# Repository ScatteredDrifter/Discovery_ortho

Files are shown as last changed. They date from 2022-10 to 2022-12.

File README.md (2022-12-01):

# SO[H] ORTHO!

A 52 key (4x14) ortholinear keyboard, powered by an RP2040

This is a fork of [Horizon by skarrmann](https://github.com/skarrmann/horizon)

Used License [MIT](/LICENSE)

 ---
This keyboard is a grid of 1U keys with optional hotswap, breakout for LED-backlighting.



## Status :: 
- prototypes arrived and **working**
- Case to be tested 
- untested LEDs
- untested LED-Pinout
- working encoder  

---

## Features :: 
- QMK and Vial Support
- Support for Choc-Switches **only**!
- Choc-spacing 
- Hotswap for Choc-Switches 
- built with rp2040 and additional flash storage allowing for plenty of combos, layers, led matrices etc.
- easy to order with jlcpcb --> check release for files 
- support for encoder in the middle  
- additional pinouts for further modifications 
- middle part features several layouts

## Layout :: 

This pcb features different layouts that are configured within VIAL for easy usage. See below for available Layout-Options. 

As for the case, there are 6 screw holes for mounting a panel in the middle to cover the electronics. 

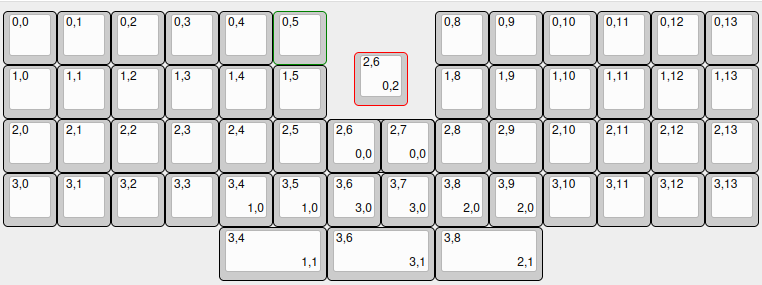
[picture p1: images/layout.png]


## Firmware :: 

the pre-compiled file for Vial and the whole Qmk-userspace for this keyboard can be found [here](/firmware/)

To enter the bootloader - which is necessary in order to flash a new firmware - you'll have to bridge the two contacts located in the middle of the front-pcb. In later revisions there might be actual buttons, for the first revision I was not able to get them to fit on there. Bridge both contacts for a short amount of time in order to boot the mcu to bootloader. It should show up as a regular usb-stick in your file explorer now and you can drag the .utf onto this usb-stick. Once done it will restart and use your newly flashed firmware!

## Images of PCB ::





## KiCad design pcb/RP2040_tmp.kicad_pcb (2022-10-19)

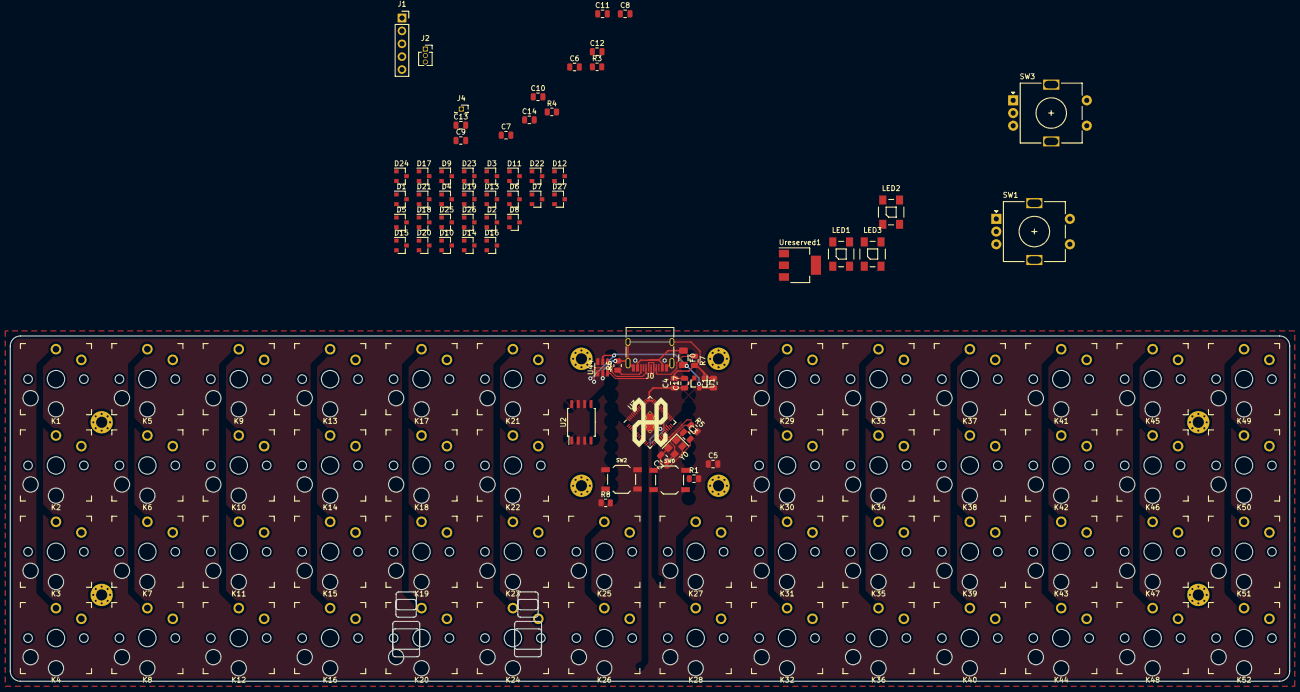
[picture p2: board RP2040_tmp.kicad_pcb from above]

Board: 2 copper layers, 252.0 x 68.0 mm, 129 parts (1 on the bottom side), 99 nets.

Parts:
C1, C4, C17: 10u; C_0805_2012Metric
C2, C3: 22pf; C_0805_2012Metric
C5, C6, C7, C9, C11, C12, C13, C14: 100n; C_0805_2012Metric
C8, C10: 1u; C_0805_2012Metric
D1, D2, D3, D4, D5, D6, D7, D8, D9, D10, D11, D12, D13, D14, D15, D16, D17, D18, D19, D20, D21, D22, D23, D24, D25, D26, D27: BAV70; SOT-23
F0: polyfuse; Fuse_1206_3216Metric
H1, H2, H3, H4, H5, H6, H7, H8: Hole_Pad; Mount_M2
J0: USB_C_Receptacle_USB2.0; USB_C_Receptacle_HRO_TYPE-C-31-M-12
J1: BREAKOUT; PinSocket_1x05_P2.54mm_Vertical
J2: Conn_01x03_Male; PinSocket_1x03_P1.27mm_Vertical
J4: Conn_01x01_Male; PinSocket_1x01_P1.27mm_Vertical
K1, K2, K3, K4, K5, K6, K7, K8, K9, K10, K11, K12, K13, K14, K15, K16, K17, K18, K19, K20, K21, K22, K23, K24, K25, K26, K27, K28, K29, K30, K31, K32, K33, K34, K35, K36, K37, K38, K39, K40, K41, K42, K43, K44, K45, K46, K47, K48, K49, K50, K51, K52: KEYSW; Kailh_socket_PG1350_optional
LED1, LED2, LED3: WS2812B
LOGO1: Logo-Bottom; Logo_Horizon_Small
LOGO2: Logo-Top; Logo_Horizon_H
R1, R5: 1k; R_0805_2012Metric
R3, R4: 27; R_0805_2012Metric
R6, R7: 5.1k; R_0805_2012Metric
R8: 10k; R_0805_2012Metric
SW0, SW2: RESET; SW_SPST_TL3342
SW1, SW3: RotaryEncoder_Switch; RotaryEncoder_Alps_EC11E-Switch_Vertical_H20mm
U1: XC6206 smaller footprint; SOT-23
U2: W25Q128JVS; SOIC-8_5.23x5.23mm_P1.27mm
U3: RP2040; RP2040-QFN-56
U44: SRV05-4; SOT-23-6
Ureserved1: larger footprint, more mA available; SOT-223-3_TabPin2
Y0: 12MHZ Crystal; Crystal_SMD_3225-4Pin_3.2x2.5mm

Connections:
+1V1: C6.1, C7.1, C8.1, J4.1, U3.23 (DVDD), U3.45 (VREG_VOUT), U3.50 (DVDD)
+3V3: C4.1, C5.1, C9.1, C10.1, C11.1, C12.1, C13.1, C14.1, C17.1, J1.2, R8.2, U1.2 (VO), U2.8 (VCC), U3.1 (IOVDD), U3.10 (IOVDD), U3.22 (IOVDD), U3.33 (IOVDD), U3.42 (IOVDD), U3.43 (ADC_AVDD), U3.44 (VREG_IN), U3.48 (USB_VDD), U3.49 (IOVDD)
+5V: C1.1, F0.2, J2.1, LED1.1 (VCC), LED2.1 (VCC), LED3.1 (VCC), U1.3 (VI), U44.5 (VP)
/QSPI_SCLK: U2.6 (CLK), U3.52 (QSPI_SCLK)
/QSPI_SD0: U2.5 (DI(IO0)), U3.53 (QSPI_SD0)
/QSPI_SD1: U2.2 (DO(IO1)), U3.55 (QSPI_SD1)
/QSPI_SD2: U2.3 (IO2), U3.54 (QSPI_SD2)
/QSPI_SD3: U2.7 (IO3), U3.51 (QSPI_SD3)
/QSPI_SS: R1.1, U2.1 (~CS), U3.56 (QSPI_SS)
/RUN: J1.1, R8.1, SW2.2, U3.26 (RUN)
/SWCLK: J1.5, U3.24 (SWCLK)
/SWD: J1.4, U3.25 (SWD)
/USB_D+: J0.A6 (D+), J0.B6 (D+), R3.1, U44.4 (IO3)
/USB_D-: J0.A7 (D-), J0.B7 (D-), R4.1, U44.3 (IO2)
/XIN: C2.1, U3.20 (XIN), Y0.3
/XOUT: R5.1, U3.21 (XOUT)
/~USB_BOOT: R1.2, SW0.2
COL0: K1.2, K2.2, K3.2, K4.2, U3.37 (GPIO25)
COL1: K5.1, K6.1, K7.1, K8.1, U3.36 (GPIO24)
COL2: K9.2, K10.2, K11.2, K12.2, U3.35 (GPIO23)
COL3: K13.1, K14.1, K15.1, K16.1, U3.34 (GPIO22)
COL4: K17.2, K18.2, K19.2, K20.2, U3.32 (GPIO21)
COL5: K21.1, K22.1, K23.1, K24.1, U3.31 (GPIO20)
COL6: K25.2, K26.2, SW1.S2, U3.30 (GPIO19)
COL7: K27.1, K28.1, SW3.S1, U3.29 (GPIO18)
COL8: K29.2, K30.2, K31.2, K32.2, U3.28 (GPIO17)
COL9: K33.1, K34.1, K35.1, K36.1, U3.27 (GPIO16)
COL10: K37.2, K38.2, K39.2, K40.2, U3.18 (GPIO15)
COL11: K41.1, K42.1, K43.1, K44.1, U3.17 (GPIO14)
COL12: K45.2, K46.2, K47.2, K48.2, U3.15 (GPIO12)
COL13: K49.1, K50.1, K51.1, K52.1, U3.14 (GPIO11)
GND: C1.2, C2.2, C3.2, C4.2, C5.2, C6.2, C7.2, C8.2, C9.2, C10.2, C11.2, C12.2, C13.2, C14.2, C17.2, J0.A1 (GND), J0.A12 (GND), J0.B1 (GND), J0.B12 (GND), J0.S1 (SHIELD), J1.3, J2.2, LED1.3 (GND), LED2.3 (GND), LED3.3 (GND), R6.2, R7.2, SW0.1, SW1.C, SW2.1, SW3.C, U1.1 (GND), U2.4 (GND), U3.19 (TESTEN), U3.57 (GND), U44.2 (VN), Y0.2, Y0.4
LED_GLOW: J2.3, LED1.4 (DIN), U3.8 (GPIO6)
unnamed: C3.1, R5.2, Y0.1
unnamed: D1.1 (A), K1.1
unnamed: D1.2 (A), K5.2
unnamed: D2.1 (A), K2.1
unnamed: D2.2 (A), K6.2
unnamed: D3.1 (A), K3.1
unnamed: D3.2 (A), K7.2
unnamed: D4.1 (A), K4.1
unnamed: D4.2 (A), K8.2
unnamed: D5.1 (A), K9.1
unnamed: D5.2 (A), K13.2
unnamed: D6.1 (A), K10.1
unnamed: D6.2 (A), K14.2
unnamed: D7.1 (A), K11.1
unnamed: D7.2 (A), K15.2
unnamed: D8.1 (A), K12.1
unnamed: D8.2 (A), K16.2
unnamed: D9.1 (A), K17.1
unnamed: D9.2 (A), K21.2
unnamed: D10.1 (A), K18.1
unnamed: D10.2 (A), K22.2
unnamed: D11.1 (A), K19.1
unnamed: D11.2 (A), K23.2
unnamed: D12.1 (A), K20.1
unnamed: D12.2 (A), K24.2
unnamed: D13.1 (A), SW1.S1
unnamed: D13.2 (A), SW3.S2
unnamed: D14.1 (A), K25.1
unnamed: D14.2 (A), K27.2
unnamed: D15.1 (A), K26.1
unnamed: D15.2 (A), K28.2
unnamed: D16.1 (A), K29.1
unnamed: D16.2 (A), K33.2
unnamed: D17.1 (A), K30.1
unnamed: D17.2 (A), K34.2
unnamed: D18.1 (A), K31.1
unnamed: D18.2 (A), K35.2
unnamed: D19.1 (A), K32.1
unnamed: D19.2 (A), K36.2
unnamed: D20.1 (A), K37.1
unnamed: D20.2 (A), K41.2
unnamed: D21.1 (A), K38.1
unnamed: D21.2 (A), K42.2
unnamed: D22.1 (A), K39.1
unnamed: D22.2 (A), K43.2
unnamed: D23.1 (A), K40.1
unnamed: D23.2 (A), K44.2
unnamed: D24.1 (A), K45.1
unnamed: D24.2 (A), K49.2
unnamed: D25.1 (A), K46.1
unnamed: D25.2 (A), K50.2
unnamed: D26.1 (A), K47.1
unnamed: D26.2 (A), K51.2
unnamed: D27.1 (A), K48.1
unnamed: D27.2 (A), K52.2
unnamed: J0.A5 (CC1), R7.1
unnamed: J0.B5 (CC2), R6.1
unnamed: LED1.2 (DOUT), LED2.4 (DIN)
unnamed: LED2.2 (DOUT), LED3.4 (DIN)
unnamed: R3.2, U3.47 (USB_DP)
unnamed: R4.2, U3.46 (USB_DM)
ROW0: D1.3 (K), D5.3 (K), D9.3 (K), D16.3 (K), D20.3 (K), D24.3 (K), U3.7 (GPIO5)
ROW1: D2.3 (K), D6.3 (K), D10.3 (K), D13.3 (K), D17.3 (K), D21.3 (K), D25.3 (K), U3.6 (GPIO4)
ROW2: D3.3 (K), D7.3 (K), D11.3 (K), D14.3 (K), D18.3 (K), D22.3 (K), D26.3 (K), U3.9 (GPIO7)
ROW3: D4.3 (K), D8.3 (K), D12.3 (K), D15.3 (K), D19.3 (K), D23.3 (K), D27.3 (K), U3.12 (GPIO9)
VBUS: F0.1, J0.A4 (VBUS), J0.A9 (VBUS), J0.B4 (VBUS), J0.B9 (VBUS)

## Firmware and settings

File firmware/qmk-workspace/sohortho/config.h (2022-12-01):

// Copyright 22 ScatteredDrifter / evelynsta

#pragma once

#include "config_common.h"

/* --- USB Device properties --- */
#define VENDOR_ID 0xFAB0
#define PRODUCT_ID 0xFAB2
#define DEVICE_VER 0x0001
#define MANUFACTURER ScatteredDrifter
#define PRODUCT SO[H]Ortho!

/* --- Matrix definition --- */
#define MATRIX_ROWS 4 
#define MATRIX_COLS 14

/* --- Matrix assignment --- */ 
#define MATRIX_COL_PINS \
    { GP24, GP25, GP2, GP3, GP4, GP7, GP23, GP13, GP17, GP16, GP18, GP19, GP20, GP21 } 
#define MATRIX_ROW_PINS \
    { GP22, GP0, GP1, GP5 } 
/* --- Encoder assignment --- */
#define ENCODER_RESOLUTION 4
#define ENCODERS_PAD_A {GP14 }
#define ENCODERS_PAD_B {GP15 }

/*#define ENCODER_DIRECTION_FLIP*/

/* --- additional settings --- */
#define DEBUG_MATRIX_SCAN_RATE
#define LAYER_STATE_16BIT
// reducing chattering, set to 0 if not necessary 
#define DEBOUNCE 5 
#define DIODE_DIRECTION COL2ROW


//#define QMK_WAITING_TEST_BUSY_PIN GP8
//#define QMK_WAITING_TEST_YIELD_PIN GP9

/* --- RP2040 specific settings */
#define RP2040_BOOTLOADER_DOUBLE_TAP_RESET
//#define RP2040_BOOTLOADER_DOUBLE_TAP_RESET_LED GP25
#define RP2040_BOOTLOADER_DOUBLE_TAP_RESET_TIMEOUT 500U

#define RGB_DI_PIN GP6

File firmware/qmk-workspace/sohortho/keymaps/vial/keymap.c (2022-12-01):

/* Derivate of elmo's firmware >>kb-elmo<mail@elmo.space>
 *
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
 * You should have received a copy of the GNU General Public License
 * along with this program.  If not, see <http://www.gnu.org/licenses/>.
 */
#include QMK_KEYBOARD_H

// defining layer_names 
#define _BL 0
#define _FL 1
#define _FFL 2

// --- /
// -- / definition of  encoder map
#if defined(ENCODER_MAP_ENABLE)
const uint16_t PROGMEM encoder_map[][NUM_ENCODERS][2] = {
    [0] =   { ENCODER_CCW_CW(KC_MS_WH_UP, KC_MS_WH_DOWN)},
    [1] =  { ENCODER_CCW_CW(RGB_HUD, RGB_HUI)},
    [2] =  { ENCODER_CCW_CW(RGB_VAD, RGB_VAI)}, 
};
#endif
const uint16_t PROGMEM keymaps[][MATRIX_ROWS][MATRIX_COLS] = {

/* Buran
   *  ┌────┬────┬────┬────┬────┐┌────┐┌────┬────┬────┬────┬────┐
   *  │ Q  │ W  │  E  │ R  │ T ││    ││ Y  │ U  │ I  │ O  │ P  │
   *  ├────┼────┼────┼────┼────┤├────┤├────┼────┼────┼────┼────┤
   *  │ A  │ S  │ D  │ F  │ G  ││    ││ H  │L(2J│ K  │ L  │ ;  │
   *  ├────┼────┼────┼────┼────┤├────┤├────┼────┼────┼────┼────┤
   *  │ Z  │ X  │ C  │ V  │ B  ││    ││ N  │ M  │ ,  │ .  │ /  │  
   *  └────┴────┴────┴────┴────┘└────┘└────┴────┴────┴────┴────┘
   *  ┌────┬────┬─────┐┌──────┐ ┌────┐ ┌──────┐┌─────┬────┬────┐
   *  │ctrl│MO1 │ GUI ││LT1Spc│ │MCR │ │ Bksp ││Ralt │Mo1 │ctrl│                                 
   *  └────┴────┴─────┘└──────┘ └────┘ └──────┘└─────┴────┴────┘
   */
   [_BL] = LAYOUT(
        ____,    	____,    	____,    	____,    	____,  		                   	____,    	____,    	____,    	____,    	____,   ____,            
        ____,    	____,    	____,    	____,    	____,  		    	            ____,    	____,    	____,    	____,    	____,   ____,    
        ____,    	____,    	____,    	____,    	____,  		____,   ____,    	____,    	____,    	____,    	____,    	____,   ____,    
        ____,    	____,    	____,    	____,    	____,  		____,   ____,    	____,    	____,    	____,    	____,    	____,   ____
    ),
    [_FL] = LAYOUT(
        ____,    	____,    	____,    	____,    	____,  		                   	____,    	____,    	____,    	____,    	____,   ____,            
        ____,    	____,    	____,    	____,    	____,  		    	            ____,    	____,    	____,    	____,    	____,   ____,    
        ____,    	____,    	____,    	____,    	____,  		____,   ____,    	____,    	____,    	____,    	____,    	____,   ____,    
        ____,    	____,    	____,    	____,    	____,  		____,   ____,    	____,    	____,    	____,    	____,    	____,   ____
    ),
    [_FFL] = LAYOUT(
        ____,    	____,    	____,    	____,    	____,  		                   	____,    	____,    	____,    	____,    	____,   ____,            
        ____,    	____,    	____,    	____,    	____,  		    	            ____,    	____,    	____,    	____,    	____,   ____,    
        ____,    	____,    	____,    	____,    	____,  		____,   ____,    	____,    	____,    	____,    	____,    	____,   ____,    
        ____,    	____,    	____,    	____,    	____,  		____,   ____,    	____,    	____,    	____,    	____,    	____,   ____
    )
};

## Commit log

2022-10-17 first commit, reduced quantity
    [Matrix_keeb.kicad_sch, RP2040_tmp.kicad_pcb, RP2040_tmp.kicad_sch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]
2022-10-19 updated pcb
    [RP2040_tmp.kicad_pcb, RP2040_tmp.kicad_sch, horizon-choc.kicad_pcb]
2022-10-26 updated pcb
    added onboard mcu
    included silkscreen resembling sun and SOHO
    added files for assembly with jlcpcb
    [Matrix_keeb.kicad_sch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]
2022-11-02 fixed issue of pcb, added assembly files for jlc
    [RP2040_tmp.kicad_sch]

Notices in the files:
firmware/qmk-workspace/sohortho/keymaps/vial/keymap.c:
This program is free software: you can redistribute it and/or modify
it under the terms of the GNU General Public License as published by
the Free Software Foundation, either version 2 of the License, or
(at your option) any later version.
